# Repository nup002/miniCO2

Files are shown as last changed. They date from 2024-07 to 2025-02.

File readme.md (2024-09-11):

# MiniCO2

The MiniCO2 is a miniature USB-powered CO2 sensor that can be used 
anywhere you need a simple indicator of CO2. Its built-in LEDs light up green, orange, or red, depending on the 
amount of CO2 in the air. The default levels can be adjusted via software to suit your needs.
<p align="center">
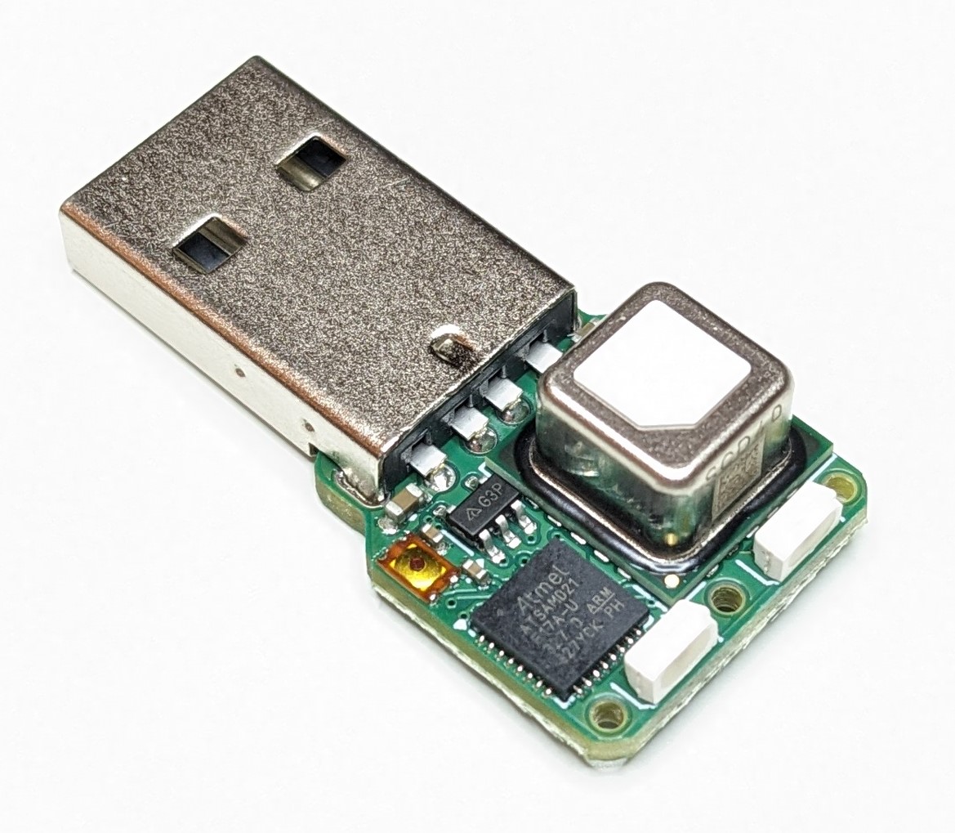
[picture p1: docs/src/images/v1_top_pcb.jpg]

</p>

The image above is of a prototype. The final version will have a USB-C connector and wireless connectivity. 

## I want one!
The MiniCO2 is under development and cannot be purchased yet. But you can register your interest by adding your email
to the bottom of this form: https://docs.google.com/forms/d/e/1FAIpQLSczLEsP1Wsz9qHPjULFHvHtzbTa30NaE-r1zrS9D4k2iNyR5Q/viewform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

Once finished, the MiniCO2 will be available for purchase on Tindie.

## Repo status
The repository is an active work in progress. Currently, only the KiCAD design files are provided. I intend to add:
 - CAD files for a 3D-printable enclosure
 - Firmware
 - Control application
 - Python example snippets on how to receive data

## Compatibility
The MiniCO2 will work with any standard USB type C port that can supply power. That means it can be plugged in nearly 
anywhere: Laptops, displays, chargers, battery banks, etc. It will also have wireless connectivity thanks to an 
ESP32-C6 module. This provides Wi-Fi, Bluetooth, Bluetooth Low Power, Thread, and Zigbee.

## Licenses
The MiniCO2 firmware is licensed under the GNU General Public License v3. The MiniCO2 hardware is licensed under 
CERN-OHL-S v2. This includes the PCB design files and enclosure design files. As an individual you are free to make your 
own MiniCO2, or to modify it, as long as these licenses are respected.

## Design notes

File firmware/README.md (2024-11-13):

# MiniCO2

This is the firmware for the MiniCO2, a miniature wireless CO2 sensor based on the Sensirion SCD40 sensor.

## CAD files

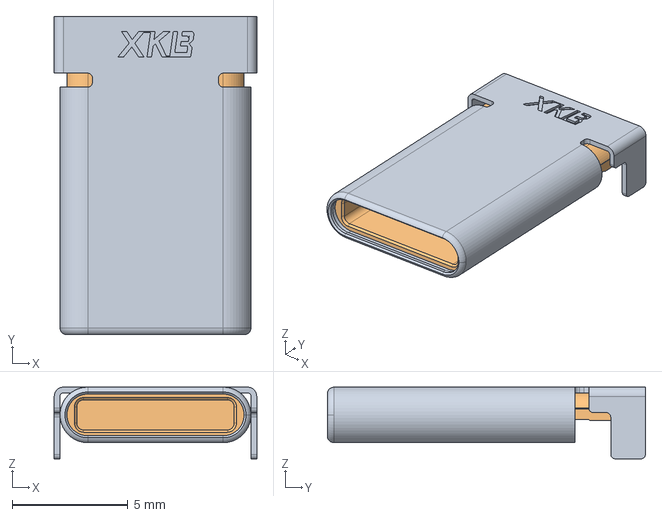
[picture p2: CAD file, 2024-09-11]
hardware/pcb/models/U261-121N-4BS2S.stp
8.75 x 13.7 x 3.10 mm

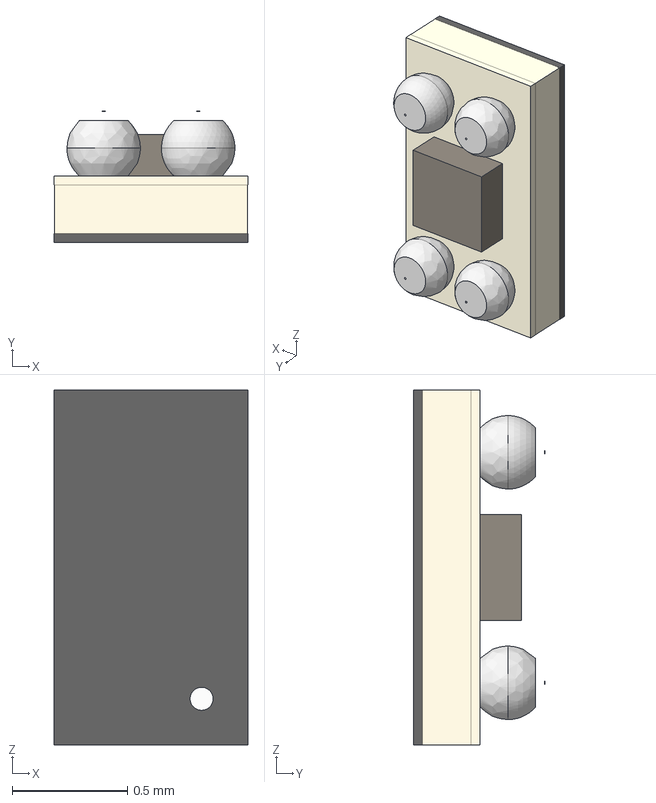
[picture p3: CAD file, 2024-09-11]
hardware/pcb/models/CSP_1508_4pins.stp
0.84 x 0.57 x 1.54 mm

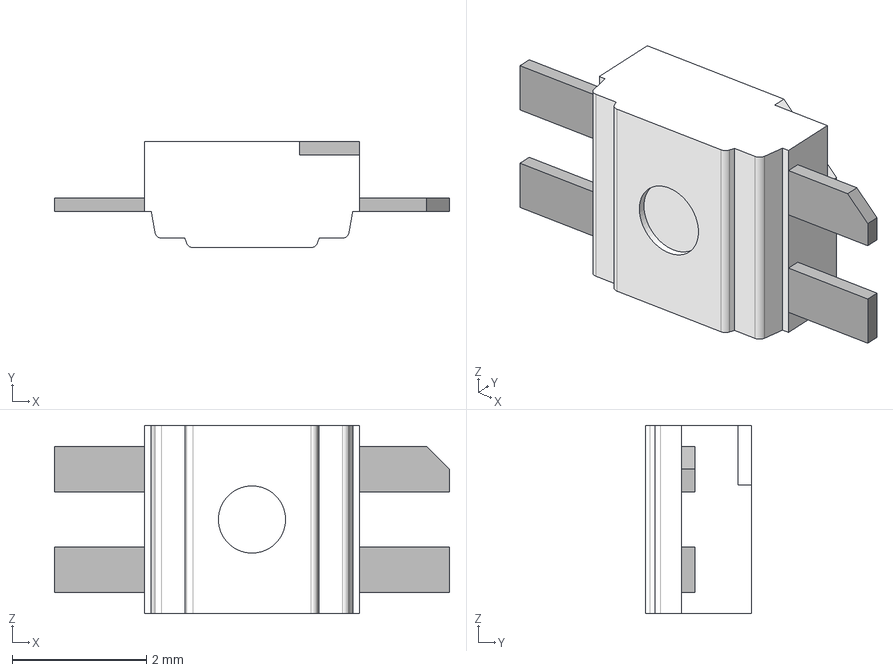
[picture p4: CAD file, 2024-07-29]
hardware/pcb/models/SK6812MINI-E v1.step
5.88 x 1.58 x 2.80 mm

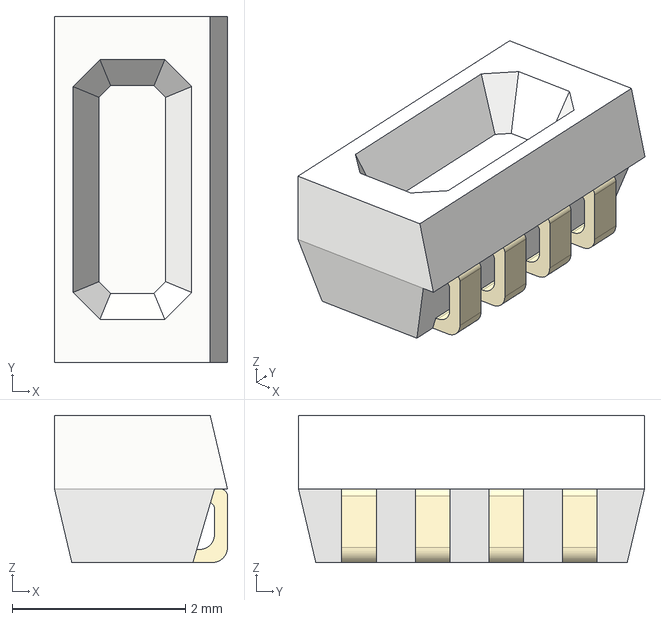
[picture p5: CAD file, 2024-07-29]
hardware/pcb/models/WS2812C-4020.step
2.00 x 4.00 x 1.70 mm

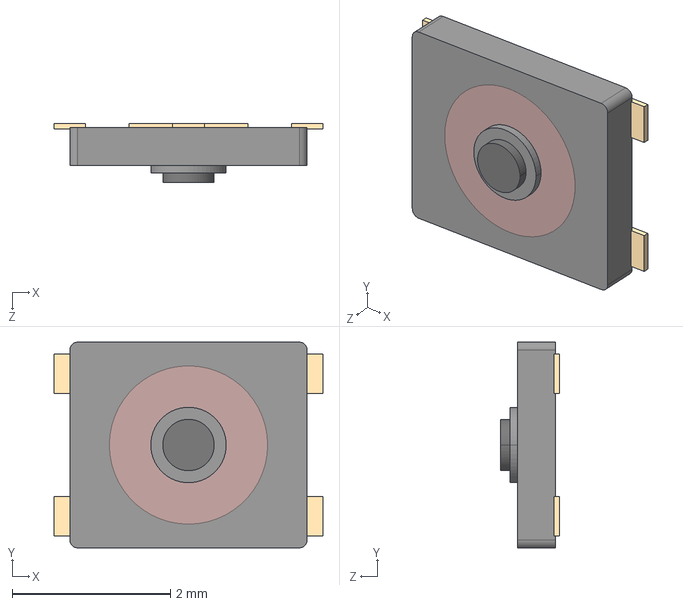
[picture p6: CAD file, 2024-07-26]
hardware/pcb/models/PANASONIC_EVPAF7B70.STEP
3.40 x 2.60 x 0.75 mm

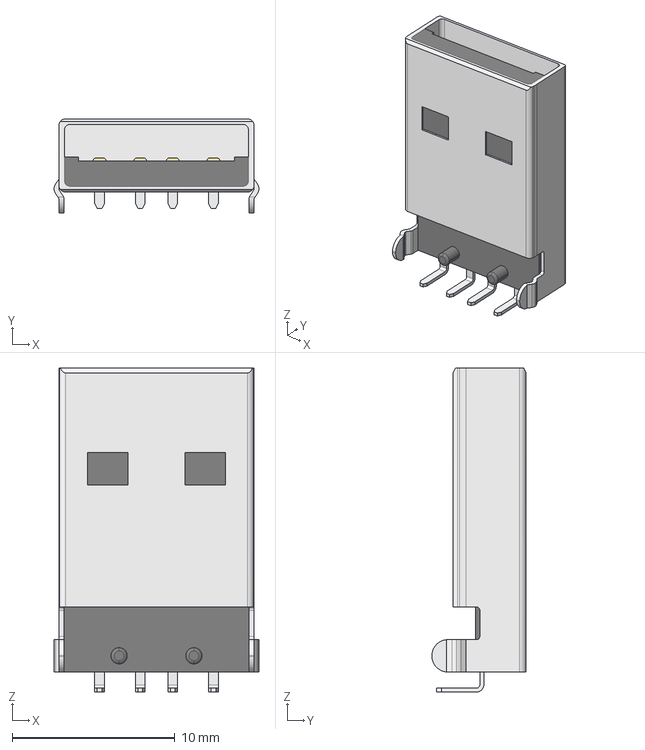
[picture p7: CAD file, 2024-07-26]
hardware/pcb/models/a-usb_a-lp-c.stp
12.6 x 5.80 x 19.9 mm

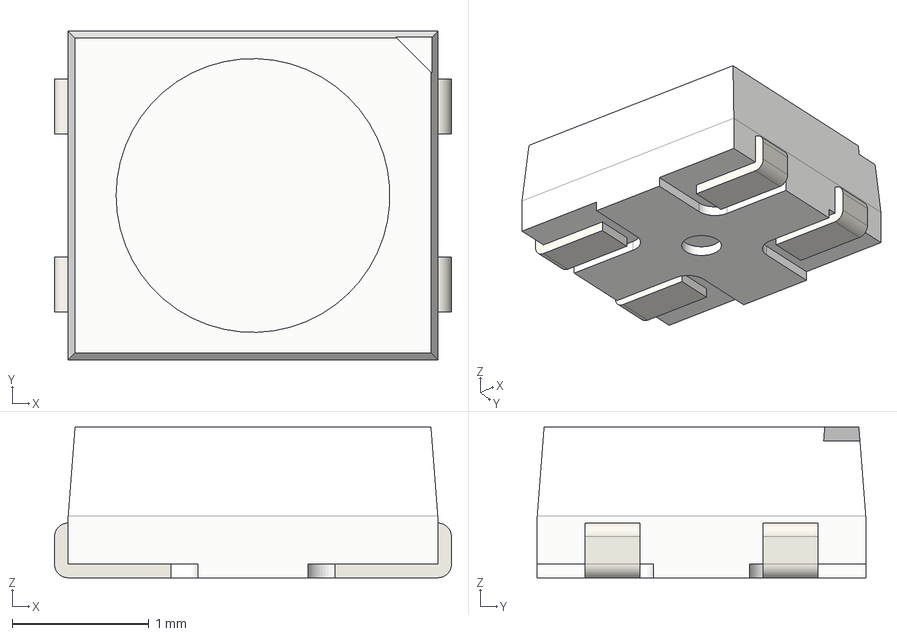
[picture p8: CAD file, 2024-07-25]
hardware/pcb/models/SK6805-2.4x2.7.step
2.90 x 2.40 x 1.10 mm
DOUT
DIN
VSS
VDD

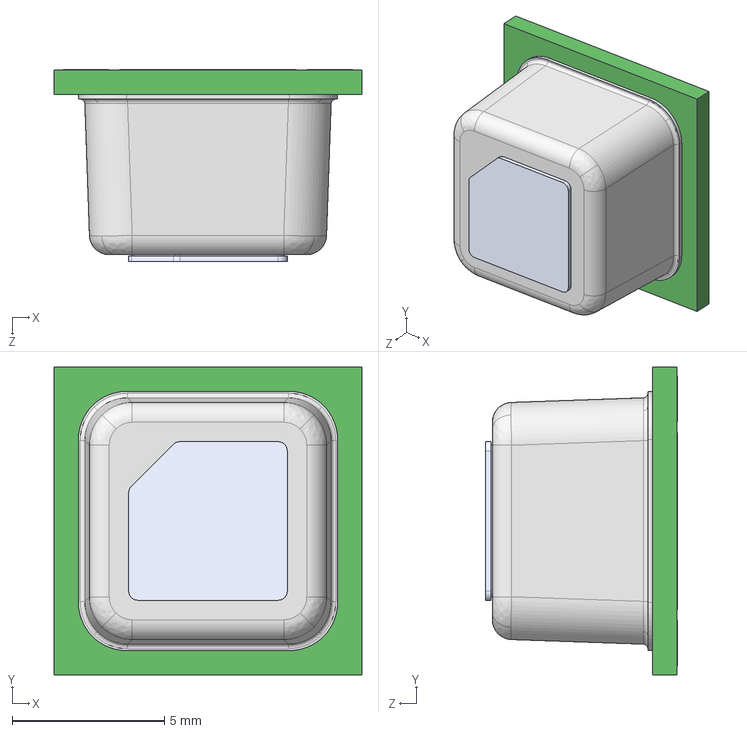
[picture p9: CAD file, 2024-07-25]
hardware/pcb/models/Sensirion_CO2_Sensors_SCD4x_STEP_file.step
10.1 x 10.1 x 6.31 mm

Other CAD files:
hardware/pcb/models/WS2812C-4020.stl

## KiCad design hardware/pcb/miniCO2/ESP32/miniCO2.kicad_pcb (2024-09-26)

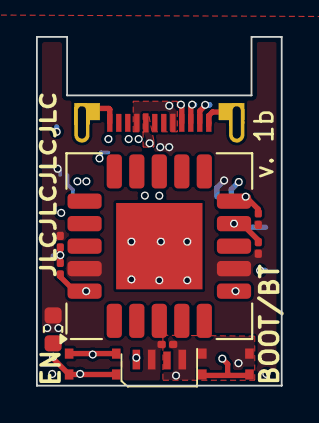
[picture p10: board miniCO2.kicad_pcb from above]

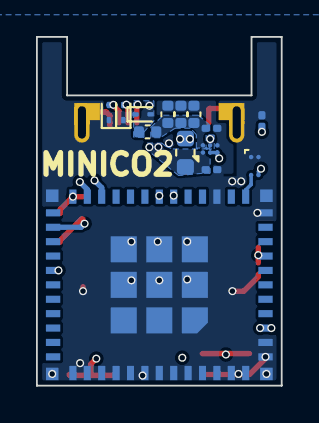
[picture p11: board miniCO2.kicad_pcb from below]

Board: 4 copper layers, 13.6 x 19.4 mm, 25 parts (14 on the bottom side), 14 nets.

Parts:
C1, C2, C3: 2.2uF; C_0201_0603Metric
C4: 10uF; C_0603_1608Metric
C5, C6, C8: 22uF; C_0402_1005Metric
C7: 100nF; C_0201_0603Metric
D1: WS2812C-4020
D2, D3: ESD9B3.3ST5G; D_SOD-923
D4: ESD9B5.0ST5G; D_SOD-923
F1: BSMD0402L-075; C_0402_1005Metric
L1: 0.47uH; L_0603_1608Metric
P1: USB_C_Plug_USB2.0; U261-121N-4BS2S
R1, R4, R6, R7: 5.1k; R_0201_0603Metric
SW1, SW2: SW_Push; LS75C2D-T
U1: ESP32-C6-MINI-1/U; ESP32-C6-MINI-1
U2: LM3281; Texas_DSBGA-6_0.95x1.488mm_Layout2x3_P0.4mm
U3: SCD40-D-R2; Sensirion_SCD4x-1EP_10.1x10.1mm_P1.25mm_EP4.8x4.8mm
U4: SIT1552AI-JE-DCC-32.768D; SiT1552CSP_0.84x1.54

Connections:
+3.3V: C1.2, C4.2, C7.1, D1.2 (VDD), L1.2, R1.2, R6.2, R7.2, U1.3 (3V3), U1.22 (GPIO8), U2.A1 (FB), U3.7 (VDD), U3.19 (VDD), U4.3 (Vdd)
BOOT_MODE: SW2.2, U1.23 (GPIO9)
D+: D3.2 (A2), P1.A6 (D+), U1.18 (GPIO13/USB_D+)
D-: D2.2 (A2), P1.A7 (D-), U1.17 (GPIO12/USB_D-)
DIN: D1.1 (DIN), U1.29 (GPIO23)
EN: C2.2, R1.1, SW1.2, U1.8 (EN/CHIP_PU)
GND: C1.1, C2.1, C3.1, C4.1, C5.1, C6.1, C7.2, C8.1, D1.4 (VSS), D2.1 (A1), D3.1 (A1), D4.1 (A1), P1.A1 (GND), P1.A12 (GND), P1.B12 (GND), P1.S1 (SHIELD), R4.1, SW1.1, SW2.1, U1.1 (GND), U1.2 (GND), U1.11 (GND), U1.14 (GND), U1.36 (GND), U1.37 (GND), U1.38 (GND), U1.39 (GND), U1.40 (GND), U1.41 (GND), U1.42 (GND), U1.43 (GND), U1.44 (GND), U1.45 (GND), U1.46 (GND), U1.47 (GND), U1.48 (GND), U1.49 (GND), U1.50 (GND), U1.51 (GND), U1.52 (GND), U1.53 (GND), U2.C2 (GND), U3.6 (GND), U3.20 (GND), U3.21 (GND), U4.1 (GND), U4.4 (GND)
unnamed: P1.A5 (CC), R4.2
unnamed: L1.1, U2.B2 (SW)
unnamed: C3.2, C5.2, C6.2, C8.2, F1.2, U2.A2 (VIN)
SCL: R7.1, U1.26 (GPIO20), U3.9 (SCL)
SDA: R6.1, U1.24 (GPIO18), U3.10 (SDA)
VBUS: D4.2 (A2), F1.1, P1.A4 (VBUS), P1.B9 (VBUS), U2.B1 (MODE), U2.C1 (EN)
XOSC32K: U1.12 (GPIO0/ADC1_CH0/XTAL_32K_P), U4.2 (CLK)

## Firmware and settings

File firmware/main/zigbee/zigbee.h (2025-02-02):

#ifndef _ZIGBEE_H
#define _ZIGBEE_H

#include "esp_zigbee_core.h"

void zigbee_task(void *pvParameters);

/* Zigbee configuration */
#define INSTALLCODE_POLICY_ENABLE       false   /* enable the install code policy for security */
#define ED_AGING_TIMEOUT                ESP_ZB_ED_AGING_TIMEOUT_4MIN /* Not sure what this is. */
#define ED_KEEP_ALIVE                   3000    /* Time period after which the MINICO2 must send a signal to its parent device to confirm it is still active on the network */
#define HA_ESP_SENSOR_ENDPOINT          10      /* Home Assistance device endpoint, used for temperature and humidity measurement */
#define ESP_ZB_PRIMARY_CHANNEL_MASK     ESP_ZB_TRANSCEIVER_ALL_CHANNELS_MASK    /* Zigbee primary channel mask use in the example */

#define ESP_TEMP_SENSOR_MIN_VALUE       (-10)   /* SCD4x temp sensor min measured value (degree Celsius)   */
#define ESP_TEMP_SENSOR_MAX_VALUE       (60)    /* SCD4x temp sensor max measured value (degree Celsius)   */
#define ESP_RH_SENSOR_MIN_VALUE         (0)     /* SCD4x relative humidity sensor min measured value (%)   */
#define ESP_RH_SENSOR_MAX_VALUE         (100)   /* SCD4x relative humidity max measured value (%)          */
#define ESP_CO2_SENSOR_MIN_VALUE        (0*1E-6)    /* SCD4x CO2 sensor min measured value (fraction of 1) */
#define ESP_CO2_SENSOR_MAX_VALUE        (2000*1E-6) /* SCD4x CO2 sensor max measured value (fraction of 1) */

/* Attribute values in ZCL string format
 * The string should be started with the length of its own.
 */
#define MANUFACTURER_NAME               "\x07""MAGLAUR"
#define MODEL_IDENTIFIER                "\x07""MINICO2"

#define ESP_ZB_ZED_CONFIG()                                         \
    {                                                               \
        .esp_zb_role = ESP_ZB_DEVICE_TYPE_ED,                       \
        .install_code_policy = INSTALLCODE_POLICY_ENABLE,           \
        .nwk_cfg.zed_cfg = {                                        \
            .ed_timeout = ED_AGING_TIMEOUT,                         \
            .keep_alive = ED_KEEP_ALIVE,                            \
        },                                                          \
    }

#define ESP_ZB_DEFAULT_RADIO_CONFIG()                           \
    {                                                           \
        .radio_mode = ZB_RADIO_MODE_NATIVE,                     \
    }

#define ESP_ZB_DEFAULT_HOST_CONFIG()                            \
    {                                                           \
        .host_connection_mode = ZB_HOST_CONNECTION_MODE_NONE,   \
    }

/* Custom types */

/**
 * @brief Zigbee HA MiniCO2 clusters.
 *
 */
typedef struct esp_zb_minico2_cfg_s {
    esp_zb_basic_cluster_cfg_t basic_cfg;                           /*!<  Basic cluster configuration, @ref esp_zb_basic_cluster_cfg_s */
    esp_zb_identify_cluster_cfg_t identify_cfg;                     /*!<  Identify cluster configuration, @ref esp_zb_identify_cluster_cfg_s */
    esp_zb_temperature_meas_cluster_cfg_t temp_meas_cfg;            /*!<  Temperature measurement cluster configuration, @ref esp_zb_temperature_meas_cluster_cfg_s */
    esp_zb_humidity_meas_cluster_cfg_t hum_meas_cfg;                /*!<  Humidity measurement cluster configuration, @ref esp_zb_humidity_meas_cluster_cfg_s */
    esp_zb_carbon_dioxide_measurement_cluster_cfg_t co2_meas_cfg;   /*!<  Carbon dioxide measurement cluster configuration, @ref esp_zb_carbon_dioxide_measurement_cluster_cfg_s */
    esp_zb_on_off_cluster_cfg_t led_on_off_cfg;                     /*!<  LED on/off cluster configuration */
    esp_zb_level_cluster_cfg_t led_brightness_cfg;                  /*!<  LED brightness cluster configuration */
} esp_zb_minico2_cfg_t;
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

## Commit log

2024-07-25 miniCO2 footprints
2024-07-25 Footprints and 3D models for components
    [SK6805-2.4x2.7.step, Sensirion_CO2_Sensors_SCD4x_STEP_file.step]
2024-07-25 Routing finished
    [miniCO2.kicad_pcb, miniCO2.kicad_sch]
2024-07-26 Make prototype
    [PANASONIC_EVPAF7B70.STEP, a-usb_a-lp-c.stp, miniCO2.kicad_pcb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]
2024-07-28 Version 1 finished
    [BOM.csv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]
2024-07-29 Progress towards single-sided design
    [miniCO2.kicad_pcb]
2024-07-29 Switch to front facing LEDs
    [SK6812MINI-E v1.step, WS2812C-4020.step, WS2812C-4020.stl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]
2024-07-30 Version 1 finished and sent to production
    [BOM.csv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]
2024-07-31 Fix D1, D2 footprints
    [miniCO2-B_Cu.gbr, miniCO2-B_Mask.gbr, miniCO2-B_Paste.gbr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]
2024-09-11 Version 1a
    [BOM.csv, CSP_1508_4pins.stp, U261-121N-4BS2S.stp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]
2024-09-26 scd40 centralization
    Centralize SCD40 (shifted by 100um).
    Bump version to 1b
    [miniCO2.kicad_pcb, miniCO2.kicad_sch]
2024-11-15 LED colors set from co2 level
2024-11-17 Pulsing LEDs, device state, and more error handling
2024-11-29 Setting up zigbee support
    [partitions.csv]
2025-01-03 LED CO2 levels config
2025-02-02 LEd zigbee things
